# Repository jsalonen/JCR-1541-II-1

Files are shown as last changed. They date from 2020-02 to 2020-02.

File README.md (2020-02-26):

# JCR-1541-II-1 - A Hybrid 1541 Disk Drive and C64 Emulator in Classic Form Factor

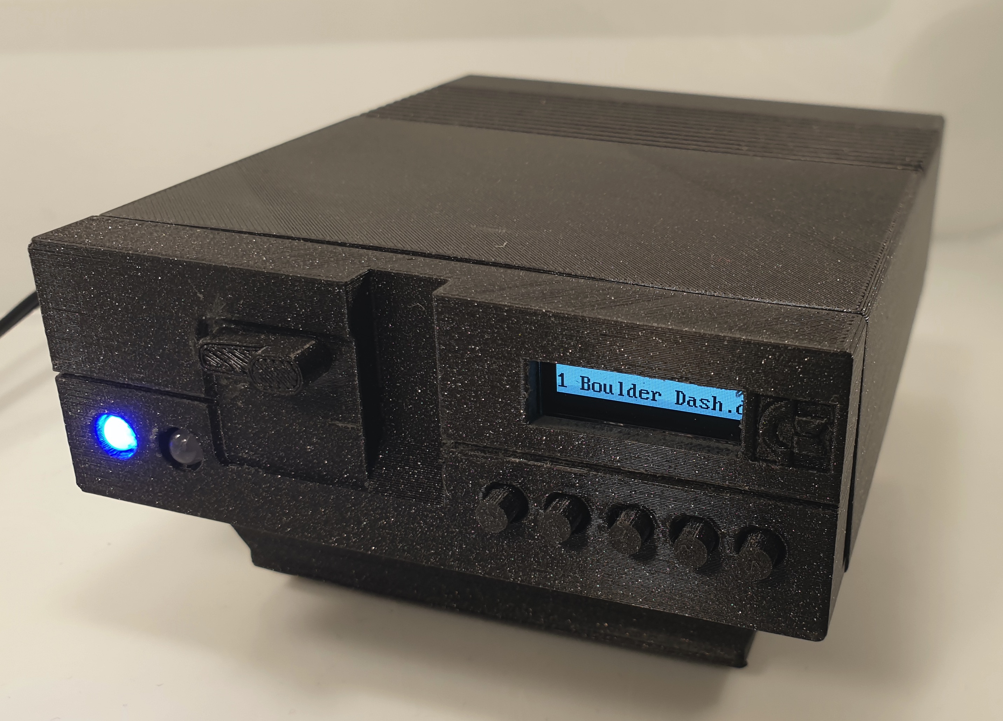
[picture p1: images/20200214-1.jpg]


**Features:**

- Cycle exact Commodore 1541 disk drive emulator (via [Pi1541](https://cbm-pi1541.firebaseapp.com/))
- Can also be used as a C64 Emulator (via [RetroPie](https://retropie.org.uk/))
- Supports serial bus chaining for connecting with other emulators or physical devices
- Power and activity leds
- Disk loading sounds
- Buttons and LED screen for changing loaded disk image
- External USB ports for easy connectivity (COMING SOON!)

See the table below for feature comparison between Pi1541 and C64 emulator modes.

| Feature | 1541 Disk Drive Mode | C64 Emulator Mode  |
|---|---|---|
| Power led | supported | supported |
| Activity led | supported | not supported |
| Disk loading sounds  | supported | not supported |
| LED screen | supported | supported |
| Front panel buttons  | supported | supported |
| Disk images via USB  | supported | not supported |
| HDMI output | supported | supported |
| USB joysticks | - | supported |
| Bluetooth joysticks  | - | supported |

## Building Instructions

### Requirements

In addition to the rest of the materials, you will need:

- A Raspberry Pi 3 Model B or B+
- Raspberry Pi USB Power Adapter. If using a third party adapter, make sure it has sufficient power output.
- microSD card

### Building PI1541 Hat

Obtain necessary materials and build a PI1541 Hat:

- Order PCB: [Pi1541 IO Adapter Rev. 4](https://www.pcbway.com/project/shareproject/Pi1541_IO_Adapter__Rev_4.html)
- Gather required components
  - Most components documented at: https://www.hackup.net/2018/07/pi1541io-revision-4/
  - Exceptions:
    - SSD1306 OLED 128x32 instead of SSD1306 OLED 128x64
    - Straight push buttons instead of right-angle push buttons

Solder components and necessary headers:

- Build the hat according to Option B setup
- For pinout compatibility, solder LED screen to use **bus 1**

### Software Setup: Pi1541

Obtain and install Pi1541: https://cbm-pi1541.firebaseapp.com/

Configure your Pi1541 to match your Pi1541 hat build (Option A or Option B setup; enable piezo buzzer)

If everything is done properly, you should be able to use 

### Printing the Case

Print all STL files contained in the case folder. Note that you need to print five buttons.

Post-process printed case as desired.

### Wiring Pi1541 Hat to the Case

(TO BE ADDED)

### Adding RetroPie Support

At this point, the device already works as a feature complete 1541 Disk Drive Emulator. With the following setup, the same physical device can also be used as a C64 emulator.

#### Install RetroPie

Obtain another SD card and flash it with [RetroPie (v4.0.2 or later)](https://retropie.org.uk/)

#### Configure OLED Display Support

For hardware pinout compatibility, make sure your PI1541 Hat is configured to use bus 1 (see table above).

| pin | PI1541 Hat (Bus 0) | PI1541 Hat (Bus 1) | RetroPie OLED |
|---|---|---|---|
| GND | (any gnd pin) | (any gnd pin) | pin 6 |
| 5V | (any 5V pin) | (any 5V pin) | pin 4 |
| SDA | pin 27 | pin 3 | pin 3 |
| SDL | pin 28 | pin 5 | pin 5 |

#### Install C64 Emulator (Vice)

- Navigate to RetroPie Setup
- From optional packages, choose and install VICE

#### Using SSD1306 OLED 128x32

Install and configure RetroPie OLED version that has been specially adjusted for this use:

    sudo apt-get update
    cd /home/pi
    git clone https://github.com/jsalonen/RetroPie-OLED.git
    cd RetroPie-OLED
    chmod 755 11.OLED.sh
    sudo ./11.OLED.sh

End result should look like this:

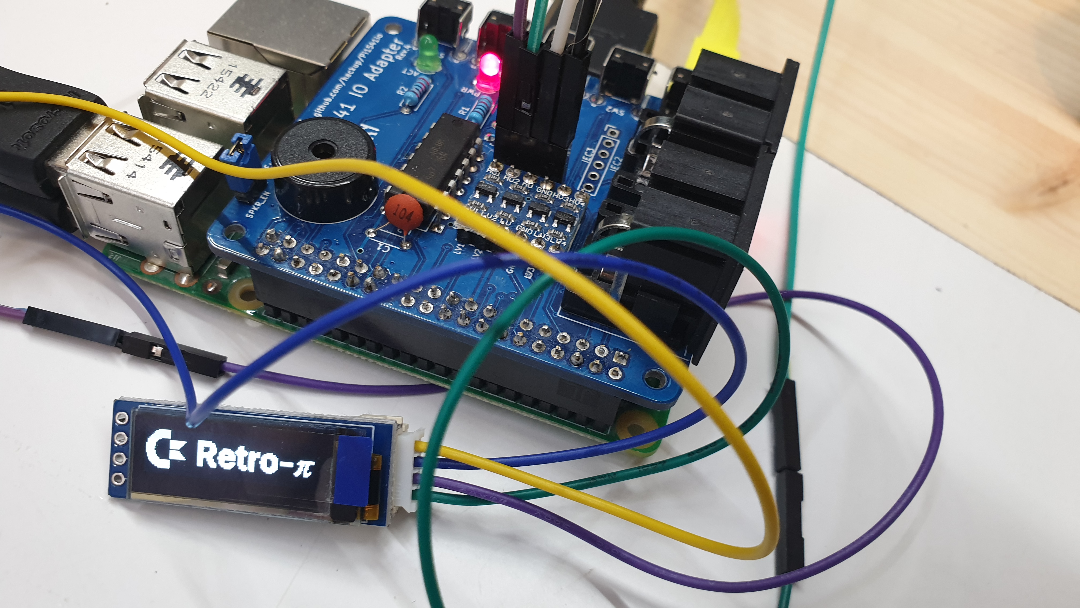
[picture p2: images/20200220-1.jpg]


#### Adding support for front panel buttons

Install [https://github.com/mholgatem/GPIOnext](GPIONext) in retropie terminal:

    cd ~
    git clone https://github.com/mholgatem/GPIOnext.git
    bash GPIOnext/install.sh

Configure the buttons with wizard (as keyboard as controller, depending what you prefer)

Run as background deamon:

    gpionext start

Reboot. When opening RetroPie, you should be able to use the buttons as a given controller

Pinout comparison table for reference:

| Label | pin | GPIO | Pi1541 function | RetroPie function |
|---|---|---|---|---|
| Switch 1 | pin 13 | GPIO27 | reset / select | joystick fire |
| Switch 2 | pin 15 | GPIO22 | previous disk / move up | joystick up |
| Switch 3 | pin 16 | GPIO23 | next disk / move down | joystick down |
| Switch 4 | pin 07 | GPIO04 | exit folder | joystick left |
| Switch 5 | pin 29 | GPIO05 | insert disk | joystick right |
| Reset | pin 38 | GPIO20 | reset | n/a |

## License and Credits

**This project is provided "as is", without warranty of any kind.**

The project includes adaptations of licensed works as follows:

- Case is adapted from [Pi1541-II Case](https://www.thingiverse.com/thing:3127040), by [chrisjh](https://www.thingiverse.com/chrisjh). Licensed under [Creative Commons - Attribution](https://creativecommons.org/licenses/by/3.0/).
- RetroPie OLED library is based on [RetroPie-OLED](https://github.com/losernator/RetroPie-OLED) by Duritz, losernator, RiNa, Yanubis, 까먹구, et al. Licensed under GNU General Public License v3.0.

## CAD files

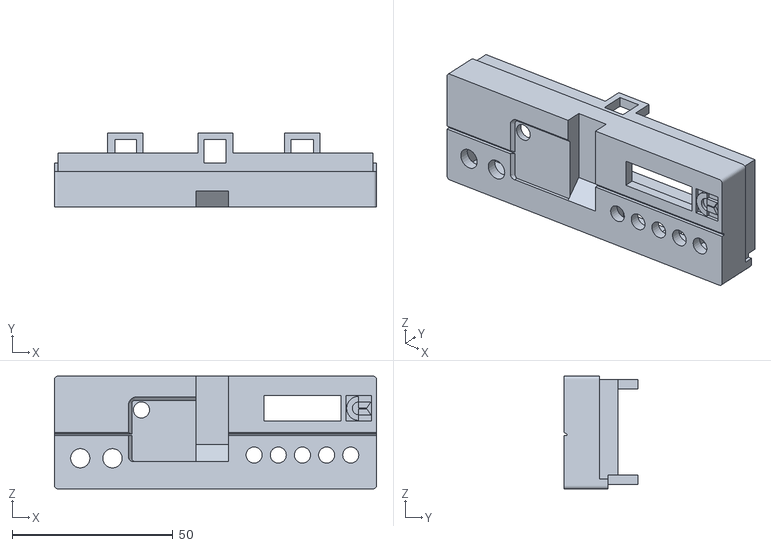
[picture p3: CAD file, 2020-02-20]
modules/Pi1541-II_Case/files/pi1541-front.stl
100.0 x 23.0 x 35.0

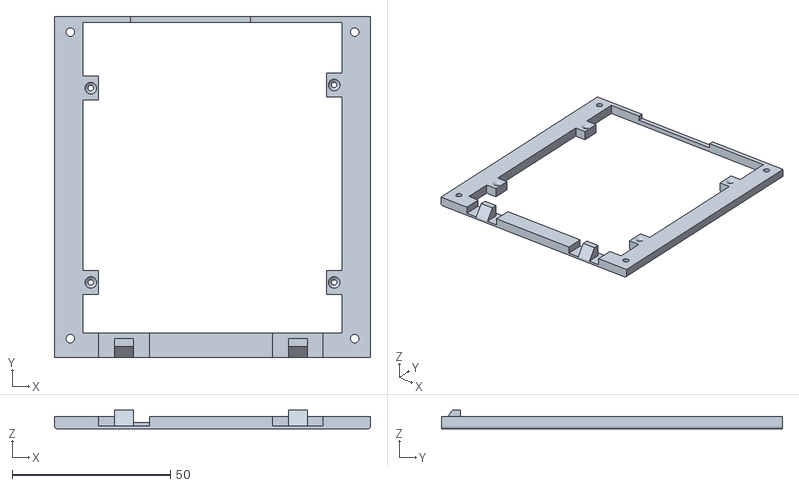
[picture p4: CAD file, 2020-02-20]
modules/Pi1541-II_Case/files/pi1541-mid.stl
100.0 x 108.0 x 6.00

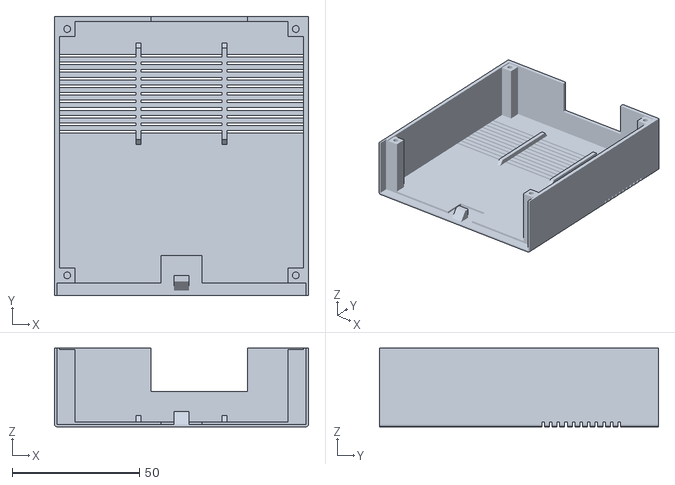
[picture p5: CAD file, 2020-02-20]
modules/Pi1541-II_Case/files/pi1541-top.stl
100.0 x 110.0 x 31.0

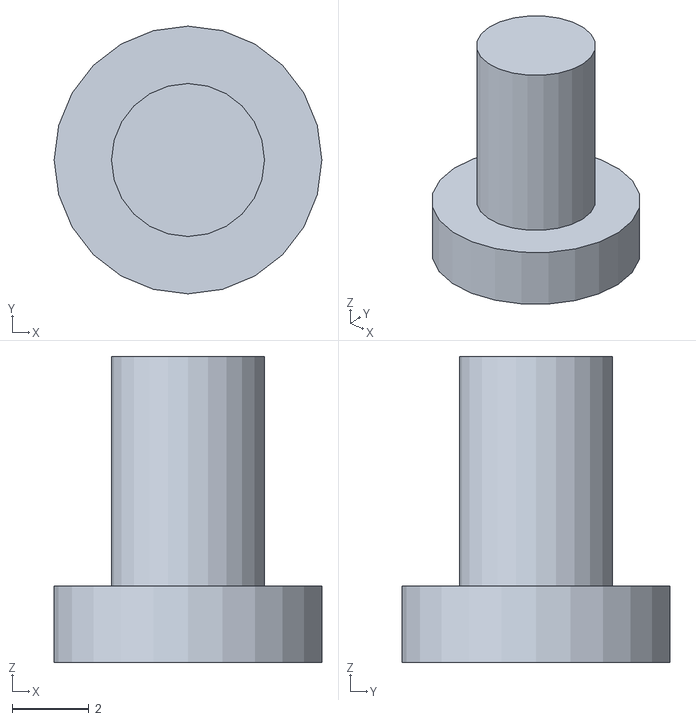
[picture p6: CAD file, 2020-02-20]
modules/Pi1541-II_Case/files/oled-button.stl
7.00 x 7.00 x 8.00

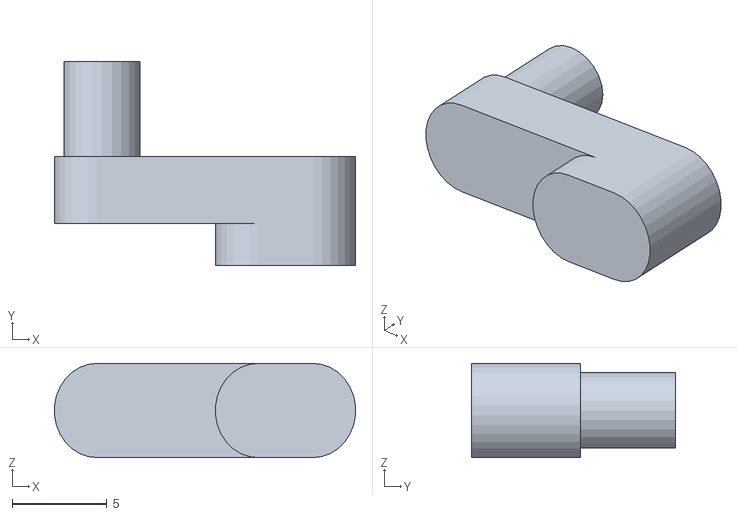
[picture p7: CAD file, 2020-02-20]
modules/Pi1541-II_Case/files/handle.stl
15.9 x 10.8 x 4.97

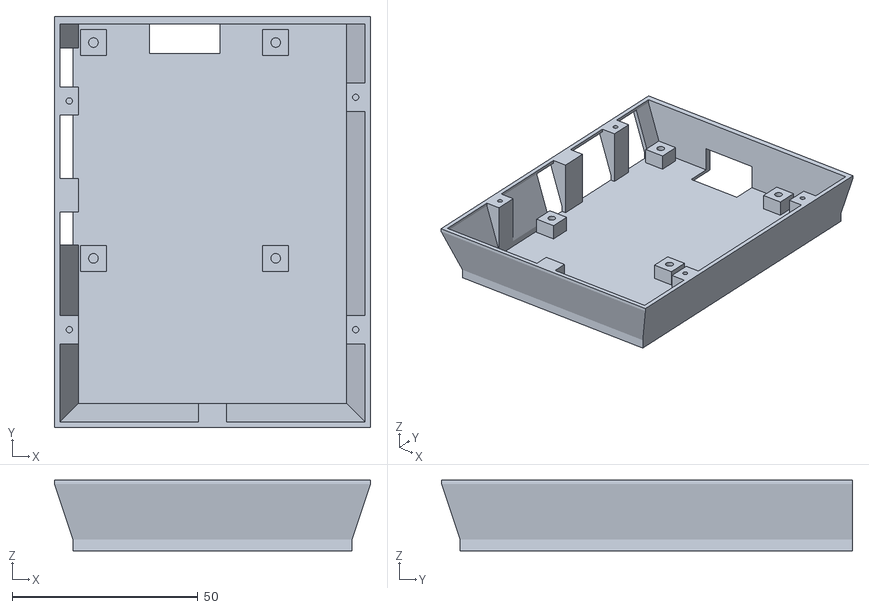
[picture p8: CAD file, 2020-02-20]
modules/Pi1541-II_Case/files/pi1541-bot.stl
85.0 x 110.5 x 19.0

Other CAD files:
modules/Pi1541-II_Case/files/Pi1541v3.1.5.1.skp

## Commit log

2020-02-20 add case models including license notes
    [Pi1541v3.1.5.1.skp, handle.stl, oled-button.stl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]
2020-02-20 doc: add retropie front panel button support initial spec
2020-02-22 Switch to GPIOnext
